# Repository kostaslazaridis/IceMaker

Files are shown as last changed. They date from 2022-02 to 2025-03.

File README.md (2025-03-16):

I came across a broken ice maker. Eager to repair it, I discovered that the original PCB was destroyed due to a burned-out IC, making it irreparable. Instead of giving up, I decided to reverse engineer the ice maker's electronics to recreate a working control board from scratch.
https://www.youtube.com/watch?v=2SMoJ112lBk&t=18s

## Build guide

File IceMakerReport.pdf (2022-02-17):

### ΠΟΛΥΤΕΧΝΕΙΟ ΚΡΗΤΗΣ

ΣΧΟΛΗ ΗΛΕΚΤΡΟΛΟΓΩΝ ΜΗΧΑΝΙΚΩΝ ΚΑΙ ΜΗΧΑΝΙΚΩΝ ΥΠΟΛΟΓΙΣΤΩΝ

### Αυτοματοποίηση παρασκευαστή παγοκύβων

### «Ειδικά Θέματα σε Συστήματα Ηλεκτρικών Μετρήσεων» (ΗΡΥ602)

### ΛΑΖΑΡΙΔΗΣ ΚΩΝΣΤΑΝΤΙΝΟΣ

### 2 Ειδικά Θέματα σε Συστήματα Ηλεκτρικών Μετρήσεων

# Πρόλογος

Η εργασία αυτή αφορά την επισκευή μιας παγομηχανής. Συγκεκριμένα, είχε καταστραφεί η πλακέτα και μέρος του κάδου. Θα ήθελα να ευχαριστήσω προσωπικά τον καθηγητή Καλαϊτζάκη Κωσταντίνο για την ευκαιρία που μου έδωσε να συμμετέχω στο μάθημα αυτό.

# Περίληψη

Το θέμα της εργασίας είναι η δημιουργία του κυκλώματος για τον έλεγχο μιας παγομηχανής. Ο μικροεπεξεργαστής που χρησιμοποιήθηκε, είναι το Arduino Nano το οποίο επεξεργάζεται τα δεδομένα από τους αισθητήρες και τις εισόδους που δίνει ο χρήστης ώστε να δημιουργήσει παγοκύβους. Στη συγκεκριμένη εργασία, φαίνεται η χρήση αλγορίθμου για την ανάγνωση της θερμοκρασίας καθώς και η εύρεση της καμπύλης θερμοκρασίας-αντίστασης από άγνωστο θερμόμετρο, η χρήση μεταλλικής γειωμένης πλάκας για την αποφυγή ηλεκτρομαγνητικών παρεμβολών, η μελέτη των εξαρτημάτων που χρησιμοποιήθηκαν, η κατασκευή της πλακέτας καθώς και ο προγραμματισμός ενός σύνθετου προβλήματος.

# Περιεχόμενα

## 1. Γενικά

Η αρχή λειτουργίας της παγομηχανής είναι η συμπίεση του αέριου(δηλ. εφαρμογή υψηλής πίεσης) και στη συνέχεια η ψύξη του μέσω μιας ψύκτρας και ενός ανεμιστήρα. Πλέον η θερμοκρασία του συμπιεσμένου αερίου βρίσκετε κοντά στην θερμοκρασία του δωματίου. Καθώς το αέριο περνάει από μία βαλβίδα η πίεση και η θερμοκρασία του μειώνονται ραγδαία. Στη συνέχεια κατευθύνεται σε σωλήνες οι οποίες βρίσκονται σε επαφή με το νερό και λόγω της διαφοράς θερμοκρασίας, το αέριο απορροφά θερμότητα από το νερό και μέσα σε λίγα λεπτά το νερό παγώνει. Για να αφαιρεθούν οι παγοκύβοι από τα μεταλλικά στοιχεία υπάρχει μια βαλβίδα η οποία εξισορροπεί τις πιέσεις. Όταν οι πιέσεις εξισορροπηθούν τα στοιχεία αυτά θερμαίνονται ελάχιστα και η εσωτερική πλευρά των παγοκύβων λιώνει, αυτό είναι αρκετό ώστε να τους επιτραπεί να «γλιστρήσουν» και να πέσουν στο κάδο περισυλλογής.

## 1. Αρχή λειτουργίας

Το παρακάτω διάγραμμα ροής περιγράφει τον αλγόριθμο λειτουργίας της παγομηχανής. Αρχικά υπάρχει μία κατάσταση InitialState στην οποία ο συμπιεστής είναι απενεργοποιημένος και η βαλβίδα αποσυμπίεσης είναι ανοιχτή, ώστε να μην υπάρχουν πιέσεις στο συμπιεστή, οι οποίες του προκαλούν μεγάλες φθορές. Επίσης σε αυτή την κατάσταση αδειάζει μια φορά το δοχείο ψύξης νερού, ώστε να μην υπάρχουν παγοκύβοι ή νερό και έτσι εξασφαλίζεται η ομαλή λειτουργία του. Όταν ο χρήστης πατήσει το κουμπί λειτουργίας, ο αλγόριθμος ελέγχει αν το δοχείο περισυλλογής παγοκύβων είναι γεμάτο. Στη περίπτωση που δεν είναι γεμάτο ξεκινά η διαδικασίας δημιουργίας παγοκύβων ανάλογα με το πιο μέγεθος έχει επιλέξει ο χρήστης. Αυτή η διαδικασία επαναλαμβάνεται έως ότου το δοχείο περισυλλογής παγοκύβων γεμίσει είτε ο χρήστης να πατήσει το διακόπτη παύσης.

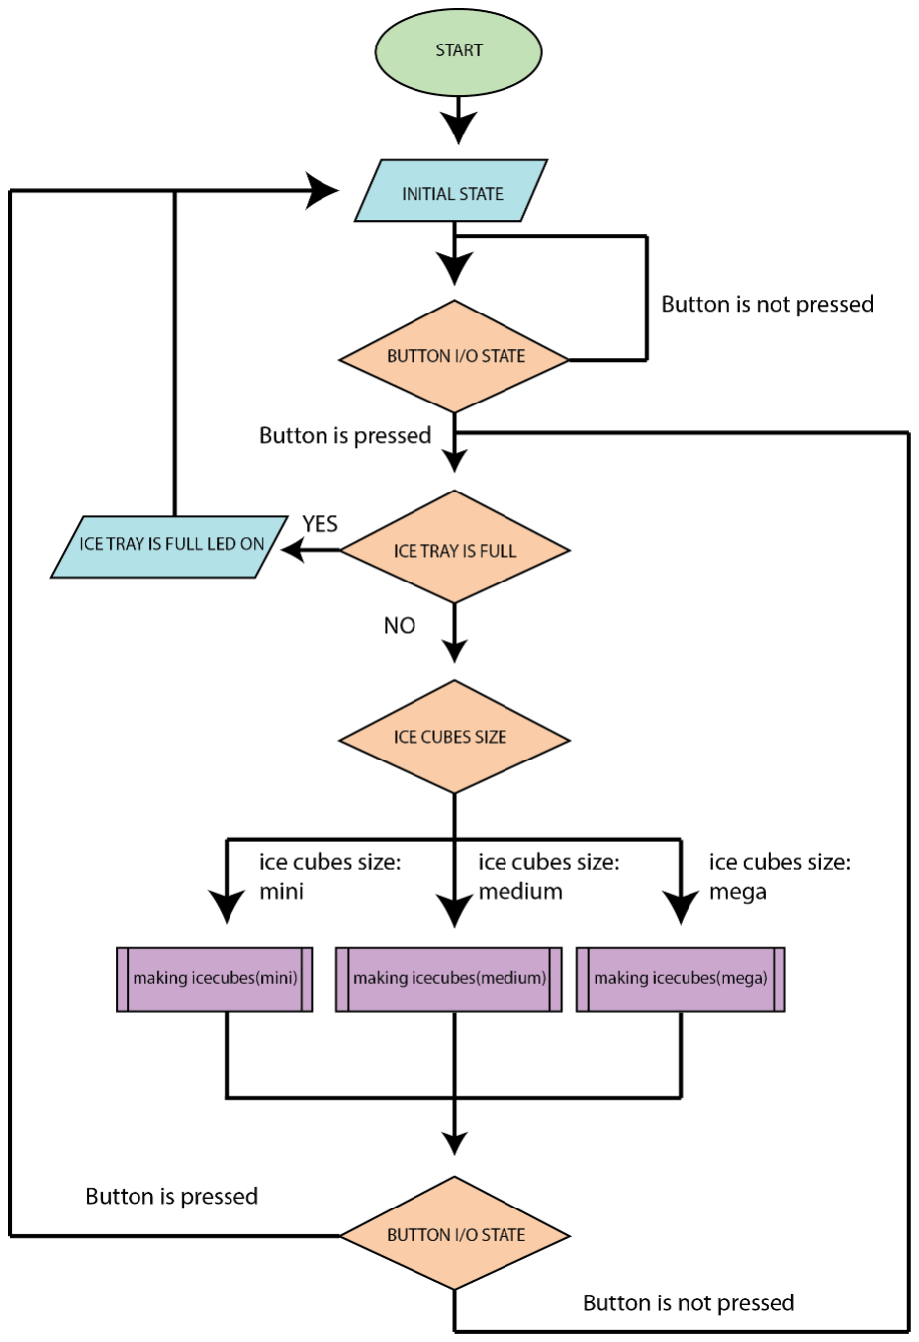
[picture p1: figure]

Εικόνα 1.1 Διάγραμμα ροής της λειτουργείας

Ο αλγόριθμος δημιουργίας παγοκύβων ξεκινά με την τοποθέτηση του δοχείου ψύξης νερού στη κατάλληλη θέση ώστε να γεμίσει με νερό. Στη συνέχεια, η αντλία λειτουργεί για καθορισμένο χρονικό διάστημα εκτός αν δεν υπάρχει νερό, οπότε απενεργοποιείτε και επιστρέφει στην InitialState. Αν υπάρχει νερό, ο συμπιεστής ενεργοποιείτε, η βαλβίδα αποσυμπίεσης απενεργοποιείτε για προκαθορισμένο χρόνο ανάλογα το μέγεθος παγοκύβων που επιθυμεί ο χρήστης. Τέλος ο συμπιεστής απενεργοποιείτε, η βαλβίδα αποσυμπίεσης ενεργοποιείτε και τα παγάκια μεταφέρονται στο καλάθι περισυλλογής.

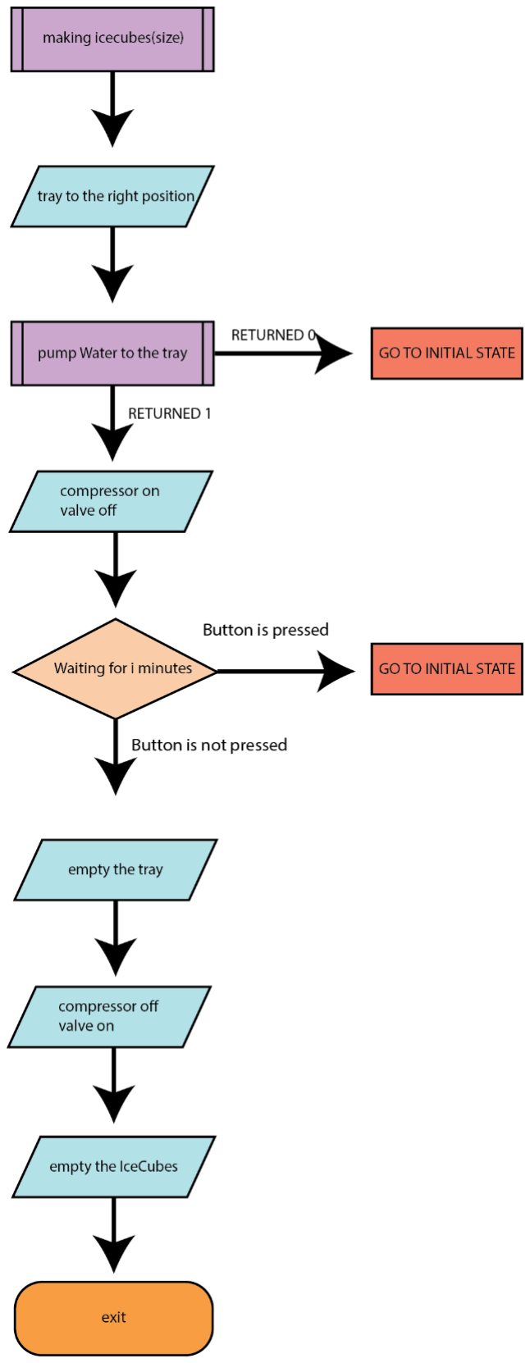
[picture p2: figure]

Εικόνα 1.2 Διάγραμμα ροής Δημιουργίας Παγοκύβων

Ο αλγόριθμος χρήσης της αντλίας αρχικά την ενεργοποιεί και σε κάθε κύκλο ρολογιού ελέγχει αν υπάρχει νερό. Στη περίπτωση που δεν υπάρχει, απενεργοποιεί την αντλία και ενημερώνει τον χρήστη.

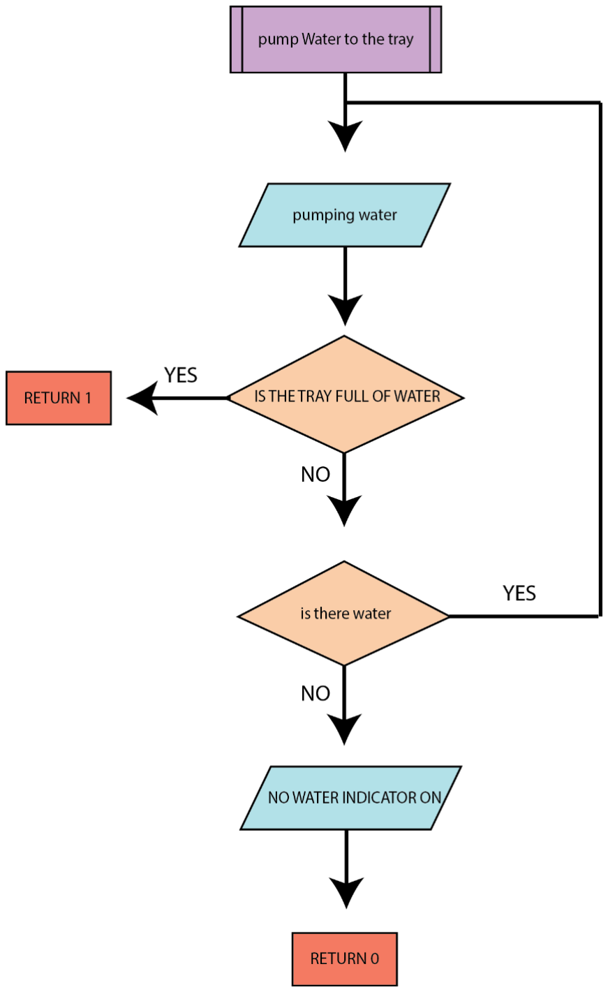
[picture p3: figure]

Εικόνα 1.3 Διάγραμμα ροής Αντλίας

## 2. Εισαγωγικά

## 2.1 Γενικές παρατηρήσεις

Στη συγκεκριμένη διατριβή, παρατηρήθηκε ότι η ηλεκτρομαγνητική ακτινοβολία λόγω του συμπιεστή δημιουργούσε παρεμβολές στον μικροεπεξεργαστή και λόγω των ευαίσθητων κυκλωμάτων «καιγόταν». Λόγω αυτής της παρεμβολής απαραίτητη θεωρείται η χρήση μίας γειωμένης επιφάνειας αλουμινίου ώστε να γειώνονται οι παρεμβολές και να μην επηρεάζουν τον μικροεπεξεργαστή. Παρατηρήθηκε επίσης ότι στην αρχή λειτουργίας της αντλίας υπήρχε μια σημαντική πτώση τάσης, η οποία έκανε επανεκκίνηση στον μικροεπεξεργαστή με αποτέλεσμα την μη ορθή εκτέλεση του προγράμματος. Κάθε relay ελέγχεται από transistor ώστε να μην απορροφηθεί περισσότερο ρεύμα από τι μπορεί να διαθέσει ο μικροεπεξεργαστής. Παρατηρήθηκε ότι αν δεν καθαριστεί αρκετά καλά το flux (πάστα που βοηθά την κόλληση) μπορεί να προκαλέσει βραχυκλώματα που θα επηρεάσουν το κύκλωμα.

## 2.2 Επικοινωνία μικροελεγκτή με τα εξαρτήματα του συστήματος

Στο παρακάτω σχήμα φαίνονται οι συνδέσεις του μικροεπεξεργαστή με τα εξαρτήματα. Τα βέλη που κατευθύνονται στο Arduino είναι οι είσοδοι ενώ τα βέλη που ξεκινούν από αυτό είναι τα εξαρτήματα που ελέγχει.

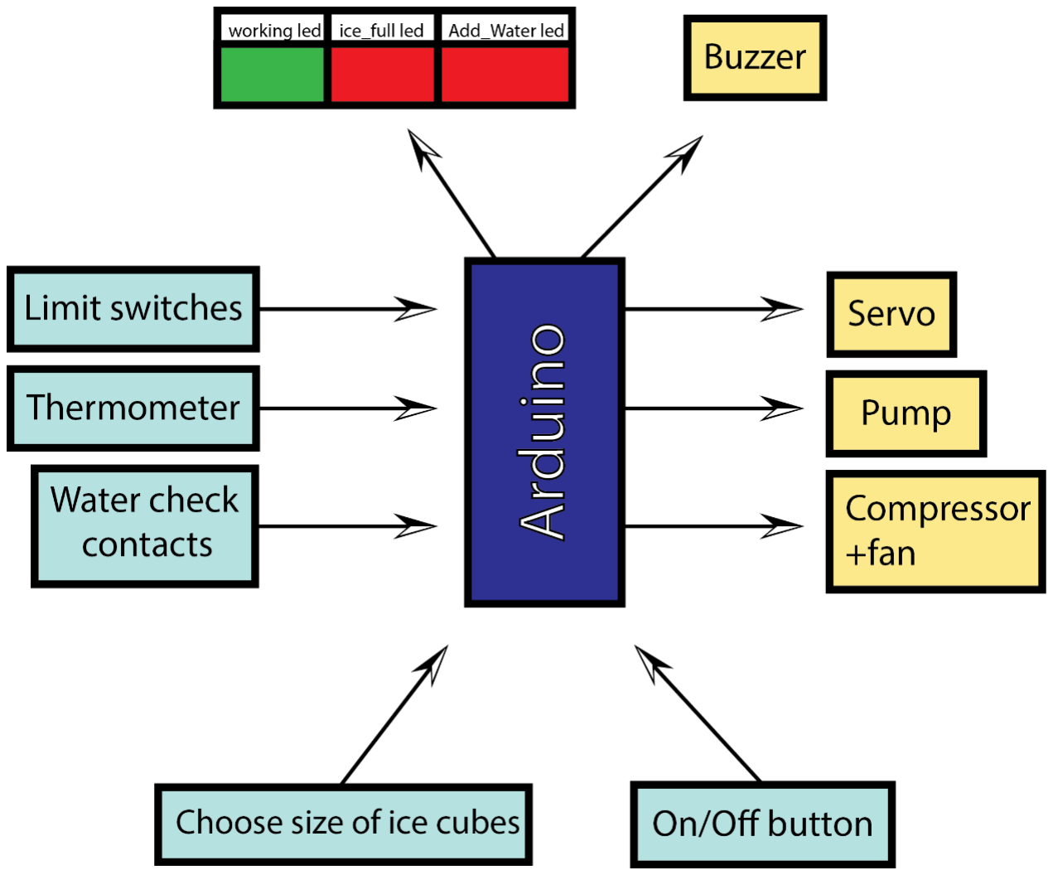
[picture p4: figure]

Εικόνα 2.1 Abstract σχέδιο κυκλώματος

## 2.3 Αισθητήρες που χρησιμοποιήθηκαν

- Αισθητήρας νερού:

Ο αισθητήρας αυτός αποτελείται από δύο ελάσματα τα οποία βρίσκονται αρκετά κοντά. Όταν διέρχεται από αυτόν τον αισθητήρα νερό, λόγω των ηλεκτρολυτών υπάρχει αντίσταση(της τάξης Mega Ohm) η οποία δημιουργείται στα δύο ελάσματα που προαναφέρθηκαν. Στη συνέχεια, ο μικροεπεξεργαστής εντοπίζει την αντίσταση αυτή, η οποία σηματοδοτεί την ύπαρξη νερού.

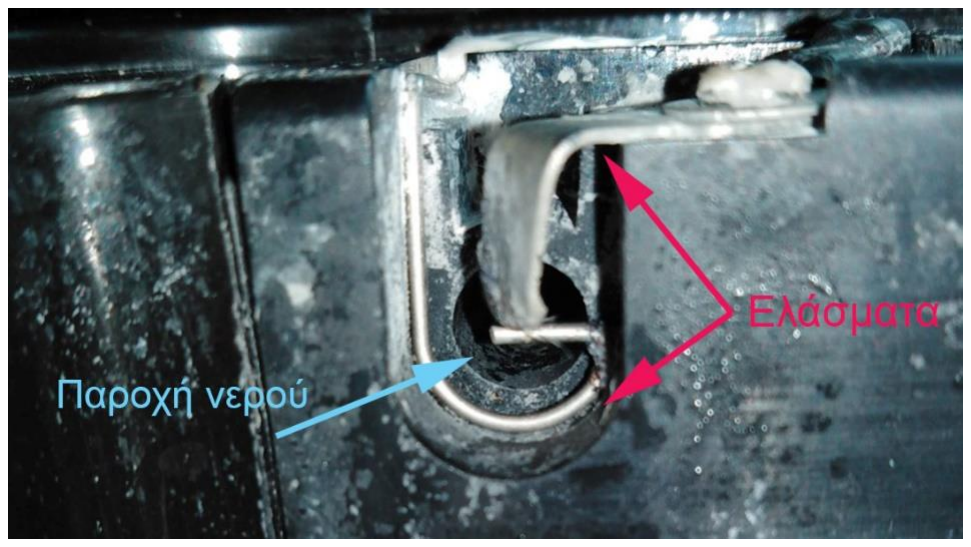
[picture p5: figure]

- Αισθητήρας θερμοκρασίας:

Ο αισθητήρας αυτός είναι ένα θερμίστορ τύπου NTC το οποίο μετρά τη θερμοκρασία στην άκρη του δοχείου περισυλλογής παγοκύβων. Όταν η θερμοκρασία αυτή προσεγγίζει τους μηδέν βαθμούς κελσίου, το οποίο σημαίνει ότι κάποιο παγάκι είτε ακουμπάει είτε είναι αρκετά κοντά, σηματοδοτείται ότι το καλάθι είναι γεμάτο με παγάκια και η διαδικασία δημιουργίας παγοκύβων πρέπει να σταματήσει.

Εικόνα 2.2 Εικόνα Αισθητήρα Νερού

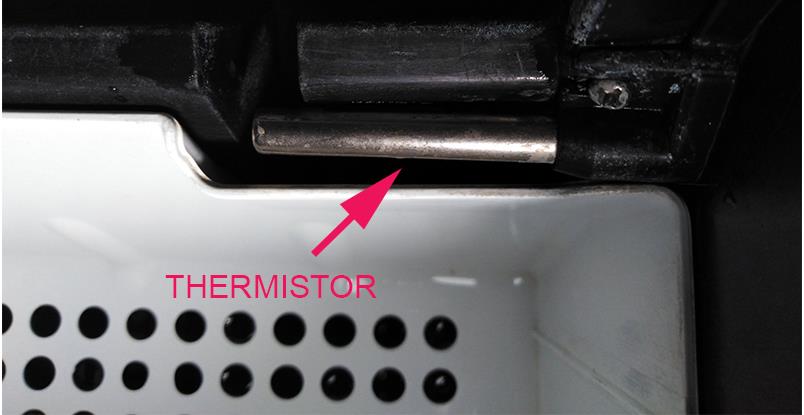
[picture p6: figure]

Εικόνα 2.3 Εικόνα Θερμίστορ

## 2.4 Μοτέρ για την κίνηση του δοχείου ψύξης νερού

- Servo 360°

Το μοτέρ που κινεί το δοχείο αυτό είναι ένα servo τριακοσίων εξήντα μοιρών, το οποίο δέχεται ένα παλμικό σήμα από τον μικροεπεξεργαστή που καθορίζει την κατεύθυνση και την ταχύτητα. Το μοτέρ αυτό αντικατέστησε το προϋπάρχον, το οποίο ήταν ένα Ac-motor που παρέμενε στις τερματικές θέσεις έως ότου άλλαζε κατεύθυνση από το μαγνητικό πεδίο. Ωστόσο, αυτός ο μηχανισμός ήταν προβληματικός στο συγκεκριμένο σύστημα, καθώς η άσκηση πίεσης στις τερματικές θέσεις τις έφθειρε και τελικά έσπασε τμήμα του κάδου. Η βλάβη αναπληρώθηκε με τρισδιάστατα σχεδιασμένο και εκτυπωμένο εξάρτημα που παρατίθεται παρακάτω.

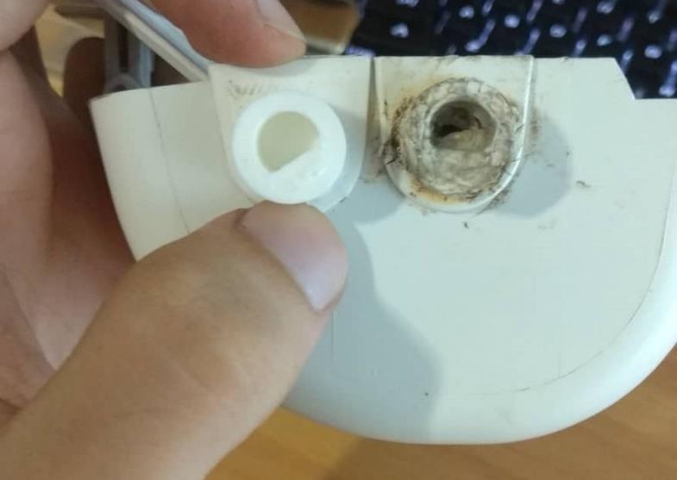
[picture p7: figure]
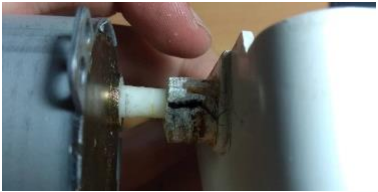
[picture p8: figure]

Εικόνα 2.4 Κάδος ψύξης νερού

## 3. Μελέτη εξαρτημάτων

### 3.1 Μελέτη κυματομορφής αντλίας και βελτιστοποίηση

Λόγω της κατασκευής της αντλίας και συγκεκριμένα στο σημείο που ενώνονται οι συλλέκτες με τα καρβουνάκια, προκύπτουν περιοδικά στην κυματομορφή του ρεύματος σημεία μηδενισμού και έπειτα απότομης αύξησης του ρεύματος. Το γεγονός αυτό ενδέχεται να επηρεάσει το τροφοδοτικό που είναι power switching supply και να του μηδενίσει την τάση εξόδου.

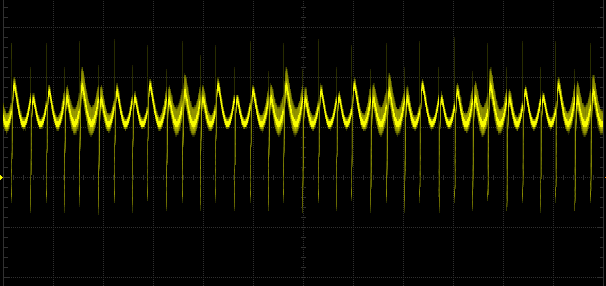
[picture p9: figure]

Για να ομαλοποιήθεί αυτή η απότομη μεταβολή του ρεύματος τοποθετήθηκε παράλληλα ένας πυκνωτής των 470μF ο οποίος επιλέχθηκε πειραματικά. Λόγω του ότι το θεμελιώδες εξάρτημα της αντλίας είναι ένα DC motor ενδέχετε να επιστρέψει τάση (kickback), για την μείωση της φθοράς του transistor τοποθετήθηκε μία δίοδος ώστε το ρεύμα αυτό να καταναλωθεί απ’τη δίοδο.

Εικόνα 3.1 Κυματομορφή ρεύματος αντλίας

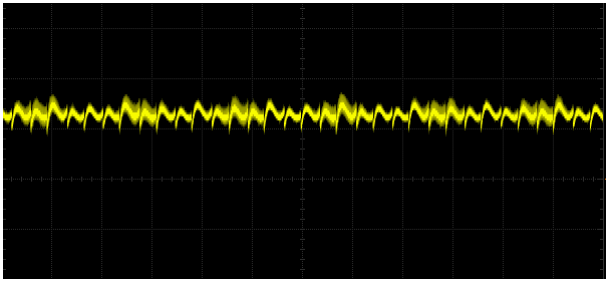
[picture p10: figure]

Εικόνα 3.2 Κυματομορφή ρεύματος αντλίας συνδεδεμένη με πυκνωτή και δίοδο παράλληλα

## 3.1 Υπολογισμός Πυκνωτή στην είσοδο του Μικροεπεξεργαστή

Παρακάτω παρατίθονται οι κυματομορφές ρεύματος της αντλίας και της τάσης του τροφοδοτικού. Παρατηρείται ότι για περίπου 6,3 ms καταναλώνει ένα μεγαλύτερο ρεύμα το οποίο δημιουργεί μία βύθιση στην τάση του τροφοδοτικού, όπως φαίνεται στην Εικόνα 3.4. Αυτή η μεταβολή της τάσης κάνει reset στο Arduino. Γι’ αυτό το λόγο στην είσοδο τάσης του μικροεπεξεργαστή τοποθετήθηκε μια δίοδος και ένας πυκνωτής (Εικόνα 3.7) ώστε όταν γίνετε βύθιση, η τάση τροφοδοσίας του μικροεπεξεργαστή να είναι σταθερή.

Εικόνα 3.3 Κυματομορφή ρεύματος αντλίας

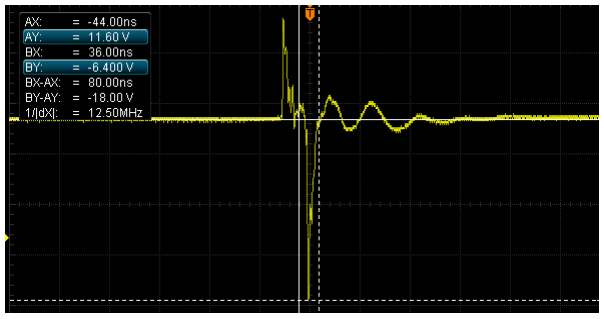
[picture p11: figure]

Εικόνα 3.4 Κυματομορφή τάσης τροφοδοσίας

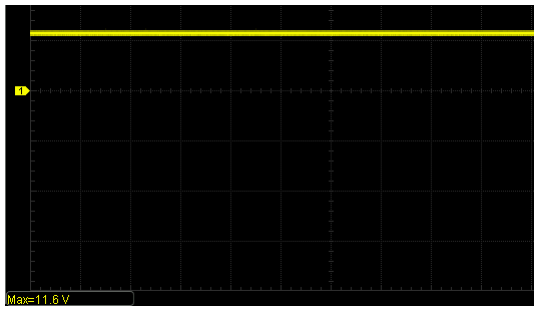
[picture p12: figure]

Εικόνα 3.5 Κυματομορφή τάσης τροφοδοσίας μικροεπεξεργαστή

Για τον υπολογισμό του κατάλληλου πυκνωτή πρέπει να παρατηρηθεί η καμπύλη αποφόρτισης του. Φαίνεται ότι σε χρόνο 0.7T η τάση του πυκνωτή έχει μειωθεί κατά 50%. Η τάση τροφοδοσίας του Arduino ιδανικά πρέπει να κυμαίνεται από 12 έως 6 volt. Με δεδομένο ότι η τάση που παρέχεται σε αυτό είναι 12 V ο πυκνωτής πρέπει να μπορεί να κρατά την τροφοδοσία έως τα 6 V για τουλάχιστον 80ns (χρόνος βύθισης τάσης λόγω αντλίας). Αξιοσημείωτο είναι ότι για τον υπολογισμό αυτό μελετάται η ακραία περίπτωση, κατά την οποία ο μικροεπεξεργαστής καταναλώνει τη μέγιστη δυνατή τιμή ρεύματος που μπορεί να του παρέχεται μέσω του regulator, πράγμα που είναι αδύνατο στο συγκεκριμένο κύκλωμα και η κατανάλωση αυτή στην πραγματικότητα είναι υπερβολικά πιο μικρή. Γι’ αυτό το λόγο η τιμή του πυκνωτή θα υπολογιστεί αποκλειστικά από την κυμματομορφή αποφόρτισης τάσης.

Αρχικά για τον υπολογισμό του πυκνωτή βρέθηκε πόσο είναι το μέγιστο ρεύμα που μπορεί να καταναλωθεί από το Arduino. Το ρεύμα αυτό είναι το μέγιστο που μπορεί να καταναλωθεί απ’ το regulator το οποίο με την σειρά του παρέχει ρεύμα στο μικροελεγκτή. Η τιμή του είναι 1.3 A και η τάση που παρέχετε στο regulator στην ακραία περίπτωση είναι 6 V. Μέσω του νόμου του Ohm βρίσκεται η αντίσταση που θα βλέπει ως φορτίο ο πυκνωτής.

RA =

V
I

=

6
1.3

= 4.61 Ω

Θεωρώντας το κύκλωμα ως RC και Τ=80ns χρόνος αποφόρτισης του πυκνωτή. Η τιμή του πυκνωτή θα υπολογιστεί από τον τύπο:

T = 0.7 ∙ RA ∙ C ⇒ C =

T
0.7 ∙ RA

=

80ns
0.7 ∙ 4.61 Ω

= 24.7 nF

Για λόγους ασφαλείας η χωρητικότητα του πυκνωτή θα αυξηθεί και η τιμή του θα είναι 1000 μF.

Εικόνα 3.6 Εκφόρτιση πυκνωτή

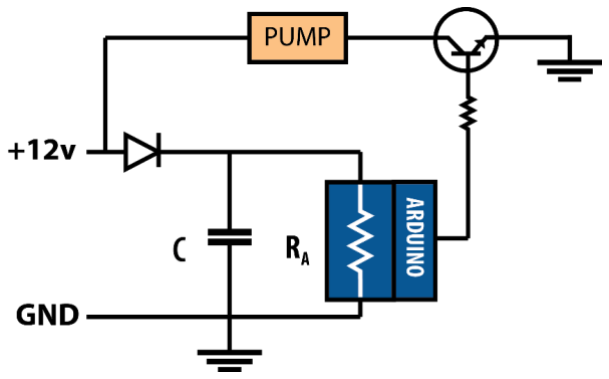
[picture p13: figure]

Εικόνα 3.7 Διάταξη Arduino Διόδου και πυκνωτή

## 3.2 Current limiting resistor LED

Για τον υπολογισμό των αντιστάσεων βρέθηκε η πτώση τάσης στο κάθε LED η οποία είναι 2.5V και το ρεύμα που είναι 3mA. Από τον νόμο του Ohm μπορεί να βρεθεί η αντίσταση που θα περιορίζει το ρεύμα:

R =

VGPIO − VF

ILED

=

5 − 2.5
0.003 = 830Ω

## 3.3 Relay και Δίοδος

Το relay ή αλλιώς ηλεκτρονόμος είναι ένας ηλεκτρικός διακόπτης (https://el.wikipedia.org/wiki/%CE%94%CE%B9%CE%B1%CE%BA%CF%8C%CF%80%CF%84%CE%B7%CF%82) που ανοίγει και κλείνει ένα ηλεκτρικό κύκλωμα (https://el.wikipedia.org/wiki/%CE%97%CE%BB%CE%B5%CE%BA%CF%84%CF%81%CE%B9%CE%BA%CF%8C_%CE%BA%CF%8D%CE%BA%CE%BB%CF%89%CE%BC%CE%B1) κάτω από τον έλεγχο ενός άλλου ηλεκτρικού κυκλώματος, στη συγκεκριμένη διατριβή τα GPIO Ports του Arduino. Αποτελείται από ένα πηνίο το οποίο όταν το διαρρέει ηλεκτρικό ρεύμα (https://el.wikipedia.org/wiki/%CE%97%CE%BB%CE%B5%CE%BA%CF%84%CF%81%CE%B9%CE%BA%CF%8C_%CF%81%CE%B5%CF%8D%CE%BC%CE%B1) το παραγόμενο μαγνητικό πεδίο (https://el.wikipedia.org/wiki/%CE%9C%CE%B1%CE%B3%CE%BD%CE%B7%CF%84%CE%B9%CE%BA%CF%8C_%CF%80%CE%B5%CE%B4%CE%AF%CE%BF) έλκει έναν οπλισμό που είναι μηχανικά συνδεδεμένος σε μια κινούμενη επαφή. Όπως προαναφέρθηκε όταν στο πηνίο του ηλεκτρονόμου υπάρχει τάση δημιουργείται μαγνητικό πεδίο. Όταν διακοπεί η τάση τότε το μαγνητικό πεδίο το οποίο υπήρχε γύρω του αντλείται από το πηνίο και δημιουργεί ένα ανάστροφο ρεύμα. Το ρεύμα αυτό περνάει μέσα από τη δίοδο και δεν επηρεάζει το υπόλοιπο κύκλωμα.

Εικόνα 3.8 Διάταξη LED αντίστασης

Εικόνα 3.9 Διάταξη relay διόδου

## 3.4 Pull-down Αντιστάσεις για τους διακόπτες

Στη συγκεκριμένη διατριβή χρησιμοποιήθηκαν διακόπτες Momentary-Push buttons όπου η συγκεκριμένη εντολή στον Μικροεπεξεργαστή δηλώνεται με λογικό «1». Αν στο διακόπτη αυτόν δεν χρησιμοποιηθεί αντίσταση ώστε το σήμα να γειώνετε, όταν δεν πιέζεται θα λαμβάνει σήματα από το γύρω ηλεκτρομαγνητικό θόρυβο το οποίο συνεπάγεται ασταθή συμπεριφορά του κυκλώματος. Γι’ αυτό το λόγο τοποθετείται μια αντίσταση στο σήμα εισόδου και στη γείωση. Η αντίσταση αυτή δεν επιτρέπεται να είναι ούτε μηδενική (λόγω του ότι θα προκαλεί βραχυκύκλωμα στη πηγή και συνεπώς καταστροφή του regulator του Arduino) αλλά ούτε και άπειρη για τους λόγους που προαναφέρθηκαν. Στον επεξεργαστή, η ελάχιστη προτεινόμενη αντίσταση που μπορεί να τοποθετηθεί είναι 20 kΩ ενώ η μέγιστη είναι 50 kΩ. Όσο πλησιάζει η αντίσταση το μέγιστο όριο, τόσο θεωρείται πιο «αδύναμη» ενώ στην περίπτωση που πλησιάζει το ελάχιστο όριο θεωρείται «δυνατή». Η επιλογή της αντίστασης βρίσκετε πειραματικά.

Εικόνα 3.10 Διάταξη pull down resistors

Εικόνα 3.11 Διάγραμμα pull down αντίστασης

## 3.5 Υπολογισμός καμπύλης αισθητήρα θερμοκρασίας αντίστασης πειραματικά

Λόγω του ότι η καμπύλη του αισθητήρα αυτού ήταν άγνωστη έπρεπε να βρεθεί πειραματικά. Στη συνέχεια έπρεπε να βρεθεί μια συνάρτηση που θα πλησιάζει αρκετά κοντά σε αυτή την καμπύλη, ώστε να μπορέσει ο μικροεπεξεργαστής να υπολογίζει τις θερμοκρασίες ανάλογα με την αντίσταση που θα έχει εκείνη την στιγμή ο αισθητήρας. Λόγω της μη γραμμικότητας της, η εύρεση της είναι αρκετά δύσκολη. Γι’ αυτό τον λόγο υπολογίστηκε μέσω του Matlab με τεχνητή νοημοσύνη.

- Αρχικά έπρεπε να γίνουν μετρήσεις θερμοκρασίας και αντίστασης του θερμομέτρου. Για να υπάρχει μια ικανοποιητική ακρίβεια στις μετρήσεις χρησιμοποιήθηκαν 2 θερμόμετρα. Στη συνέχεια αφαιρέθηκαν κάποιες μετρήσεις οι οποίες υπήρχαν λόγω σφάλματος των οργάνων. Τέλος έγινε το γράφημα των μετρήσεων και βρέθηκε η εξίσωση η οποία τείνει στην αρχική καμπύλη των μετρήσεων.

Η εξίσωση είναι ένα πολυώνυμο 5ου βαθμού:

P(R) = −0.0000039 ∙ R

5 + 0.0006 ∙ R

4 − 0.0351 ∙ R

3 + 1.026 ∙ R

2 − 15.7405 ∙ R

1 + 106.0322

Για την εύρεση της εξίσωσης χρησιμοποιήθηκε η συνάρτηση polyfit του Matlab

Εικόνα 3.12 Διάγραμμα του αισθητήρα θερμοκρασίας Θερμοκρασία-Αντίσταση. Πειραματικά αποτελέσματα(Original) και η πολυονυμική εξίσωση που το προσομοιώνει (predicted)

Εικόνα 3.13 Κώδικας Matlab

## 3.6 Υπολογισμός αντιστάσεων για τα transistors

Λόγω του ότι το κύκλωμα δεν έχει ιδιαίτερες απαιτήσεις ούτε στα ρεύματα, ούτε στις συχνότητες χρησιμοποιείται το 2n2222. Γενικά, το transistor λειτουργεί ως ενισχυτής. Όμως στη συγκεκριμένη περίπτωση το transistor χρησιμοποιείται ως διακόπτης με κατάσταση “ON” όταν η τάση στην είσοδο είναι υψηλή και “OFF” όταν είναι χαμηλή. Στα transistor υπάρχει μια περιοχή στην οποία όσο περισσότερο είναι το ρεύμα εισόδου στη βάση, τόσο μεγαλύτερο ρεύμα επιτρέπει να διαρρέεται μέσω αυτού. Στη συγκεκριμένη περίπτωση δε θα μελετηθεί αυτή η περιοχή, θα μελετηθεί μόνο στα Cut-off και στο Saturation. Μια τυπική σύνδεση του transistor φαίνεται παρακάτω όπου η τάση in συνδέεται στο GPIO port όπου R2 συμβολίζει το φορτίο.

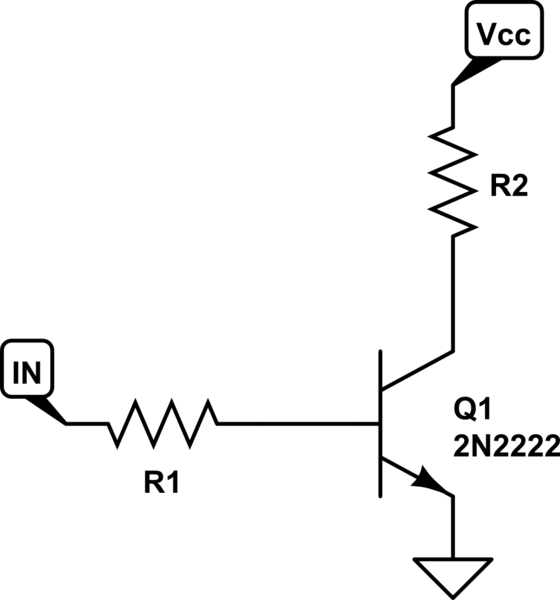
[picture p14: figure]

- Υπολογισμός αντιστάσεως εισόδου R1

Για τον υπολογισμό της αντιστάσεως εισόδου βάσης του transistor θα θεωρηθεί ότι το transistor διαχειρίζεται το μέγιστο ρεύμα, το οποίο είναι 500mA. Η τάση τροφοδοσίας Vcc είναι 12V η οποία λόγω της πτώσης τάσης που υπάρχει στο transistor θα έχει μια πτώση τάσης κατά μέγιστο 1.2V αυτό είναι ανεκτό από τα στοιχεία που ελέγχει. Λόγω του ότι η τάση μειώνεται το ρεύμα θα αυξηθεί, το οποίο είναι ανεκτό διότι τα στοιχεία καταναλώνουν περίπου το μισό ρεύμα από τι μπορεί να διαχειριστεί το transistor. Η τάση στη βάση πριν την αντίσταση είναι η τάση του GPIO port του μικροελεγκτή που είναι 5V. Το datasheet του transistor δηλώνει ότι όταν το ρεύμα Ic είναι 500mA τότε το ρεύμα της βάσης IB θα πρέπει να είναι 50mA, το μέγιστο όμως ρεύμα που μπορεί να παρέχει το Arduino είναι 40mA. Το VF είναι η πτώση τάσης λόγου της διόδου που σχηματίζεται από την βάση προς τον εκπομπό και είναι ίση με 0.7V. Με τον νόμο του Ohm μπορεί να υπολογιστεί εύκολα η αντίσταση R1.

R1 =

VGPIO − VF
IB

=

5 − 0.7 V
40mA = 107.5Ω

Εικόνα 3.14 Διάταξη transistor αντίστασης

## 3.7 Αισθητήρας Θερμοκρασίας-Νερού

O αισθητήρας θερμοκρασίας τοποθετήθηκε σε διάταξη διαιρέτη τάσης όπου η μία αντίσταση R1 είναι γνωστή. Λόγω του διαιρέτη τάσης είναι γνωστό ότι :

VOUT = VIN ∙ (

R2
R2 + R1

)

Αν αυτή η εξίσωση λυθεί ώς προς R2 :

R2 = R1 ∙ (

VIN

VOUT

− 1)

Οι αισθητήρες Θερμοκρασίας και Νερού ενώ ακολουθούν την αρχή διαφέρουν στην τιμή της γνωστής αντίστασης. Για τον αισθητήρα του νερού πρέπει να τοποθετηθεί μια μεγάλη αντίσταση R1 για να υπάρχει πτώση τάσης που θα μπορεί να διαβάσει ο μικροεπεξεργαστής, διότι η αντίσταση του νερού είναι αρκετά μεγάλη (Προσοχή: αν είναι υπερβολικά μεγάλη η αντίσταση μπορεί να μη γειώνεται σωστά το σήμα και να επηρεάζεται από παρεμβολές των ηλεκτρομαγνητικών σημάτων). Αντίθετα η αντίσταση R1 για τον αισθητήρα θερμοκρασίας πρέπει να είναι αρκετά μικρότερη ώστε να υπάρχει καλή ακρίβεια στην μετρήσεις.

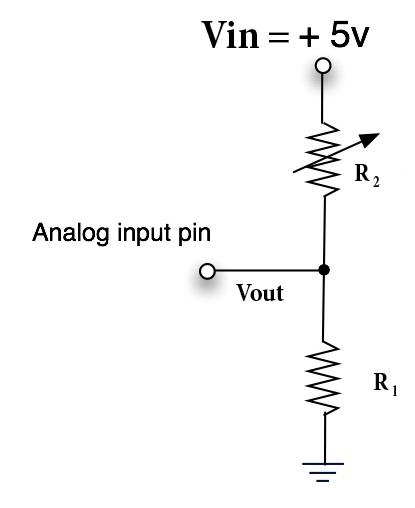
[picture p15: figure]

Εικόνα 3.15 Διάταξη διαιρέτη τάσης για αισθητήρες

## 3.8 Επιλογή μεγέθους Παγοκύβων

Λόγω του ότι χρησιμοποιούνται όλες οι ψηφιακές είσοδοι/έξοδοι του μικροεπεξεργαστή δεν είναι δυνατό να προστεθούν διακόπτες που θα επιλέγουν το μέγεθος των παγοκύβων. Γι’ αυτό το λόγο θα χρησιμοποιηθεί μια αναλογική είσοδος του Arduino στην οποία θα συνδεθούν με την παρακάτω διάταξη τρεις διακόπτες με τρεις διαφορετικές αντιστάσεις. Όταν ο χρήστης επιλέξει ένα μέγεθος, τότε βραχυκυκλώνεται μία από αυτές με μια γνωστή αντίσταση και δημιουργείται πτώση τάσης, την οποία θα διαβάζει ο μικροεπεξεργαστής μέσω της αναλογικής εισόδου και θα υπολογίζει με τον νόμο του Ohm την αντίσταση όπου επιλέχθηκε, συνεπώς ποιο μέγεθος παγοκύβων. Με την μέθοδο αυτή δίνετε η δυνατότητα να χρησιμοποιούνται αρκετοί διακόπτες σε μόνο μία είσοδο ώστε να μην δεσμεύονται οι υπόλοιπες.

Ο τύπος εύρεσης αντιστάσεως είναι ο ίδιος με τον παραπάνω που υπολογίστηκε στη παράγραφο «Αισθητήρας Θερμοκρασίας-Νερού»:

R2 = R1 ∙ (

VIN

VOUT

− 1)

Εικόνα 3.16 Διάταξη τρειών κουμπιών επιλογής

## 3.9 Μέγεθος Παγοκύβων

Έπειτα από μετρήσεις του μεγέθους παγοκύβων ανάλογα την ώρα που παγώνουν, παρατηρήθηκε ότι οι παγοκύβοι τείνουν να αυξάνονται με λογαριθμική σχέση. Το γεγονός αυτό είναι αναμενόμενο διότι καθώς αυξάνεται η διάμετρός απομακρύνεται το στέλεχος που ψύχετε απ’ το υγρής μορφής νερό. Παρακάτω παρατίθονται οι μετρήσεις και το διάγραμμα Χρόνου-Διαμέτρου:

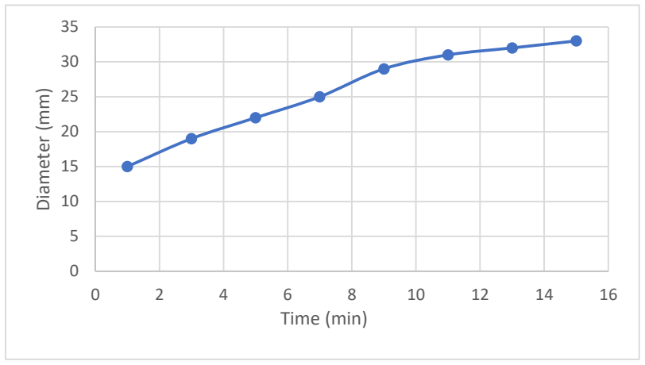
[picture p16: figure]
Diameter (mm); Time (min)

Minutes | Diameter
15 min | 33 mm
13 min | 32 mm
11 min | 31 mm
9 min | 29 mm
7 min | 25 mm
5 min | 22 mm
3 min | 19 mm
1 min | 15 mm

1

η Παρατήρηση: Λόγω του ότι το δοχείο συλλογής νερού επαναχρησιμοποιεί το νερό από τα λιωμένα παγάκια, η θερμοκρασία του νερού μειώνεται με αποτέλεσμα το νερό να παγώνει πιο γρήγορα. Συμπερασματικά τα παραπάνω αποτελέσματα δηλώνουν την γενική εκτύλιξη της διαδικασίας και όχι τους χρόνους που χρειάζεται για να παράγει ένα παγοκύβο συγκεκριμένης διαμέτρου.

2

η Παρατήρηση: Η μέγιστη διάμετρος παγοκύβου είναι συγκεκριμένη λόγω κατασκευής της παγομηχανής και δεν πρέπει να ξεπεραστεί διότι ενδέχεται να προκαλέσει βλάβη στο μηχάνημα.

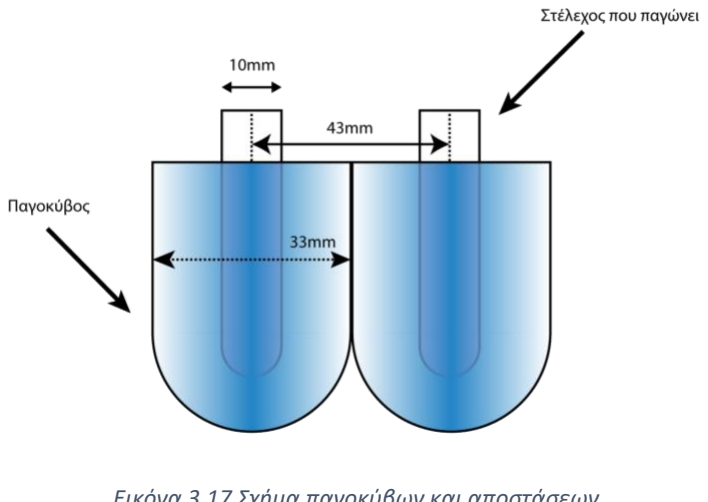
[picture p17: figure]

Εικόνα 3.17 Σχήμα παγοκύβων και αποστάσεων

## 4. Κώδικας Προγραμματισμού

## 4.1 Συνάρτηση delayForMinutesCompressor ()

Η συνάρτηση delay() που χρησιμοποιεί το Arduino αδρανοποιεί το σύστημα και δεν επιτρέπει να εκτελε-στεί άλλη εντολή μέχρι να τερματιστεί. Για τον λόγο αυτό δημιουργήθηκε μία συνάρτηση που δέχεται μια μεταβλητή float ως όρισμα, η οποία χρησιμοποιεί το εσωτερικό ρολόι του μικροεπεξεργαστή ώστε να περιμένει για το απαιτούμενο χρονικό διάστημα ελέγχοντας αν πατήθηκε ο διακόπτης παύσης. (https://forum.arduino.cc/index.php?topic=46540.0)

## 4.2 2.2 Συνάρτηση readTemp()

Η συνάρτηση αυτή είναι τύπου double και χρησιμοποιεί την εξίσωση που υπολογίστηκε παραπάνω (Υπολογισμός καμπύλης αισθητήρα θερμοκρασίας με αντίσταση). Μέσω του διαιρέτη τάσης υπολογίζεται η αντίσταση και στη συνέχεια μέσω της εξίσωσης η θερμοκρασία.

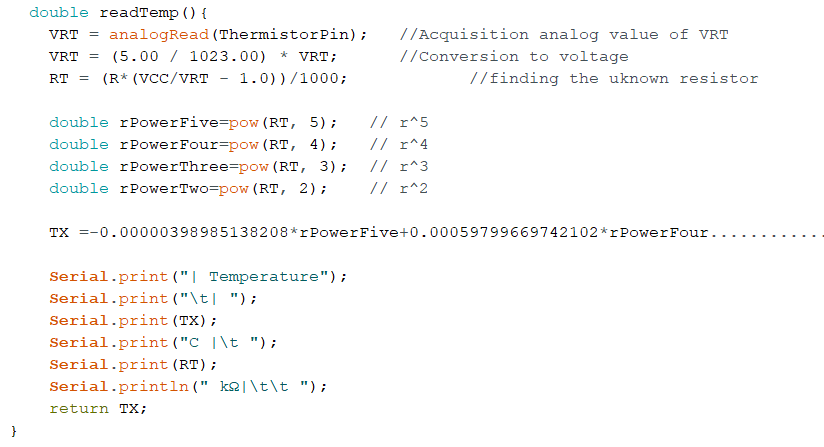
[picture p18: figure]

## 4.3 Συνάρτηση checkIfCartridgeIsFull()

Η συνάρτηση αυτή είναι τύπου Boolean και χρησιμοποιεί την παραπάνω συνάρτηση «readTemp()» ώστε όταν η θερμοκρασία είναι μικρότερη από την voudou μεταβλητή tempValueforFull να επιστρέψει true που υποδηλώνει ότι το δοχείο με τα παγάκια έχει γεμίσει.

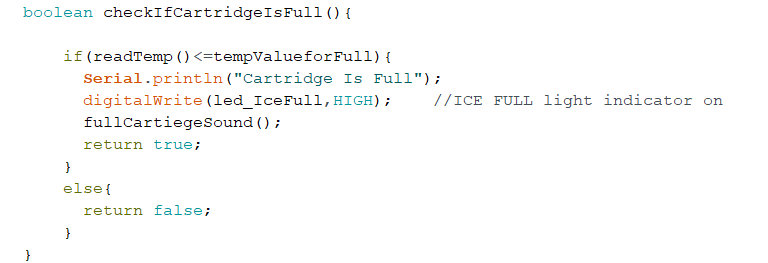
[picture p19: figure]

## 4.4 Συνάρτηση readButtonSelect()

Προκυμμένου να γίνει η επιλογή μεγέθους παγοκύβου η συνάρτηση αυτή ελέγχει την τάση στην αναλογική είσοδο και με τον νόμο του Ohm υπολογίζει την αντίσταση η οποία τοποθετείται, ανάλογα με το ποιο κουμπί πατήθηκε από τον χρήστη. Εν συνεχεία αλλάζει την μεταβλητή sizeOfIceCube που υποδηλώνει το μέγεθος των παγοκύβων.

## 4.5 Συνάρτηση toTheEndRight() - toTheEndLeft()

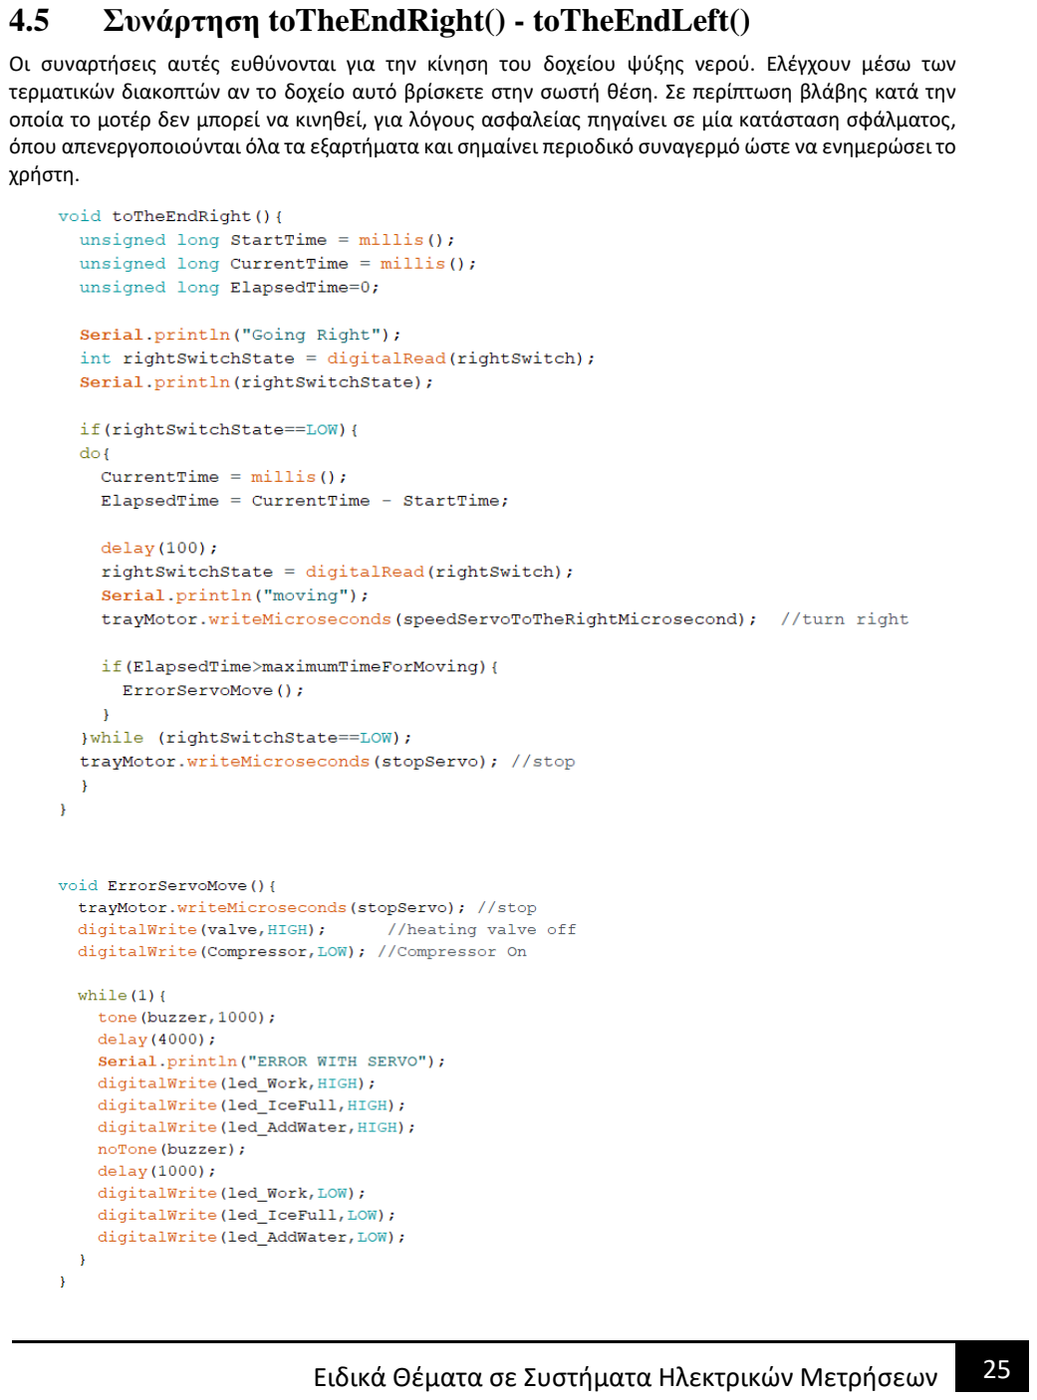
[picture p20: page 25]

Οι συναρτήσεις αυτές ευθύνονται για την κίνηση του δοχείου ψύξης νερού. Ελέγχουν μέσω των τερματικών διακοπτών αν το δοχείο αυτό βρίσκετε στην σωστή θέση. Σε περίπτωση βλάβης κατά την οποία το μοτέρ δεν μπορεί να κινηθεί, για λόγους ασφαλείας πηγαίνει σε μία κατάσταση σφάλματος, όπου απενεργοποιούνται όλα τα εξαρτήματα και σημαίνει περιοδικό συναγερμό ώστε να ενημερώσει το χρήστη.

## 4.6 Συνάρτηση checkNoWater()

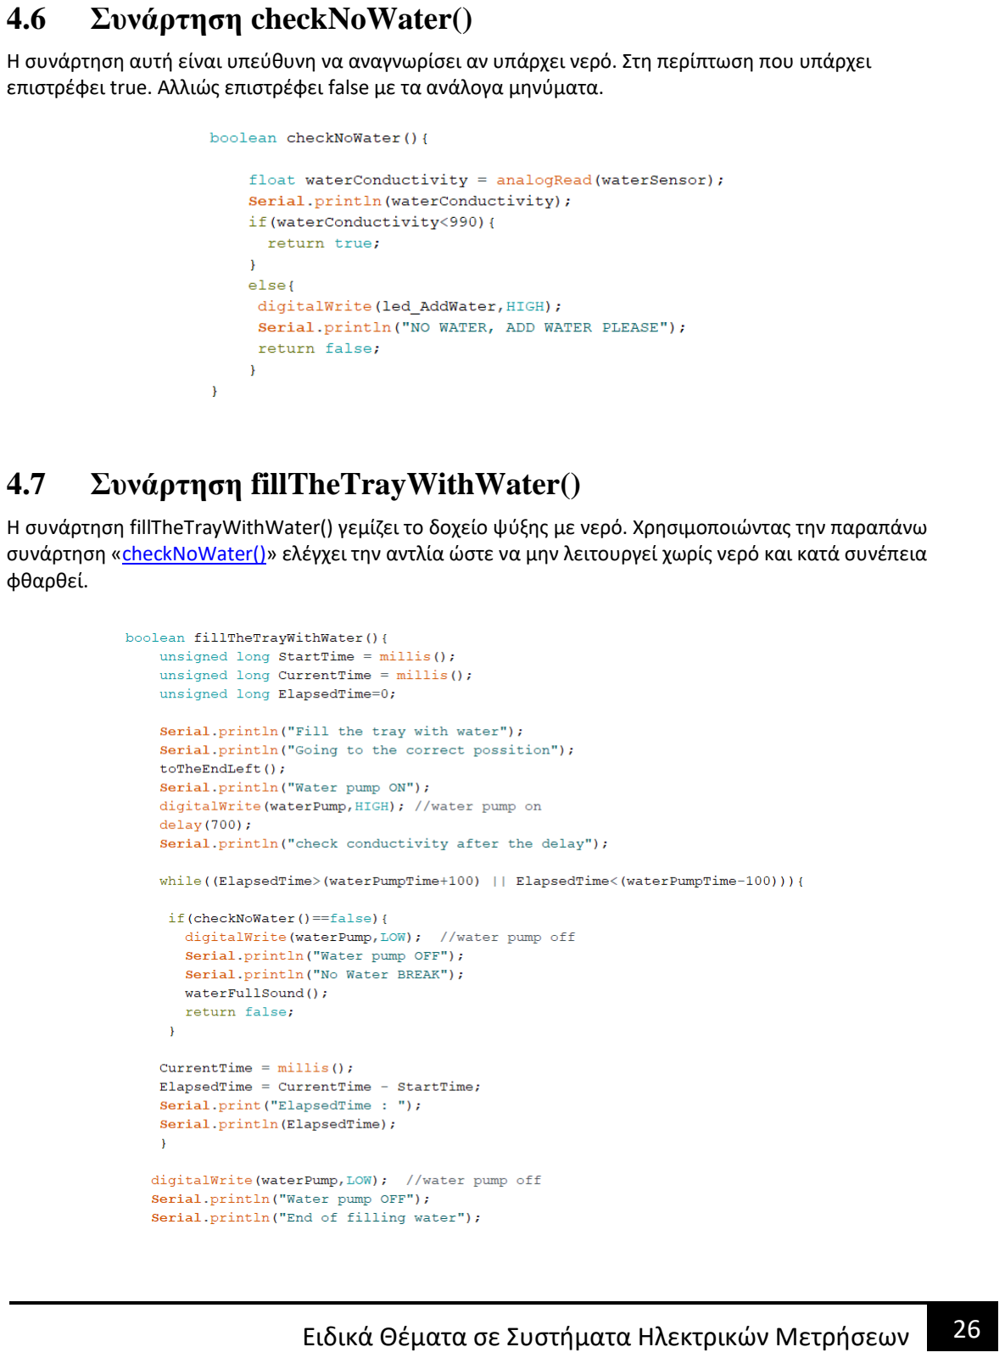
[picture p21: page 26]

Η συνάρτηση αυτή είναι υπεύθυνη να αναγνωρίσει αν υπάρχει νερό. Στη περίπτωση που υπάρχει επιστρέφει true. Αλλιώς επιστρέφει false με τα ανάλογα μηνύματα.

## 4.7 Συνάρτηση fillTheTrayWithWater()

Η συνάρτηση fillTheTrayWithWater() γεμίζει το δοχείο ψύξης με νερό. Χρησιμοποιώντας την παραπάνω συνάρτηση «checkNoWater()» ελέγχει την αντλία ώστε να μην λειτουργεί χωρίς νερό και κατά συνέπεια φθαρθεί.

## 4.8 Συνάρτηση algorithmOfIcecubes ()

Η συνάρτηση αυτή είναι ο αλγόριθμος σχηματισμού παγοκύβων.

## 4.9 Συνάρτηση MakeIceCubes ()

Η συνάρτηση αυτή συνδέει όλες τις παραπάνω συναρτήσεις ώστε να λειτουργεί σωστά η παγομηχανή

## 5. Κατασκευή πλακέτας

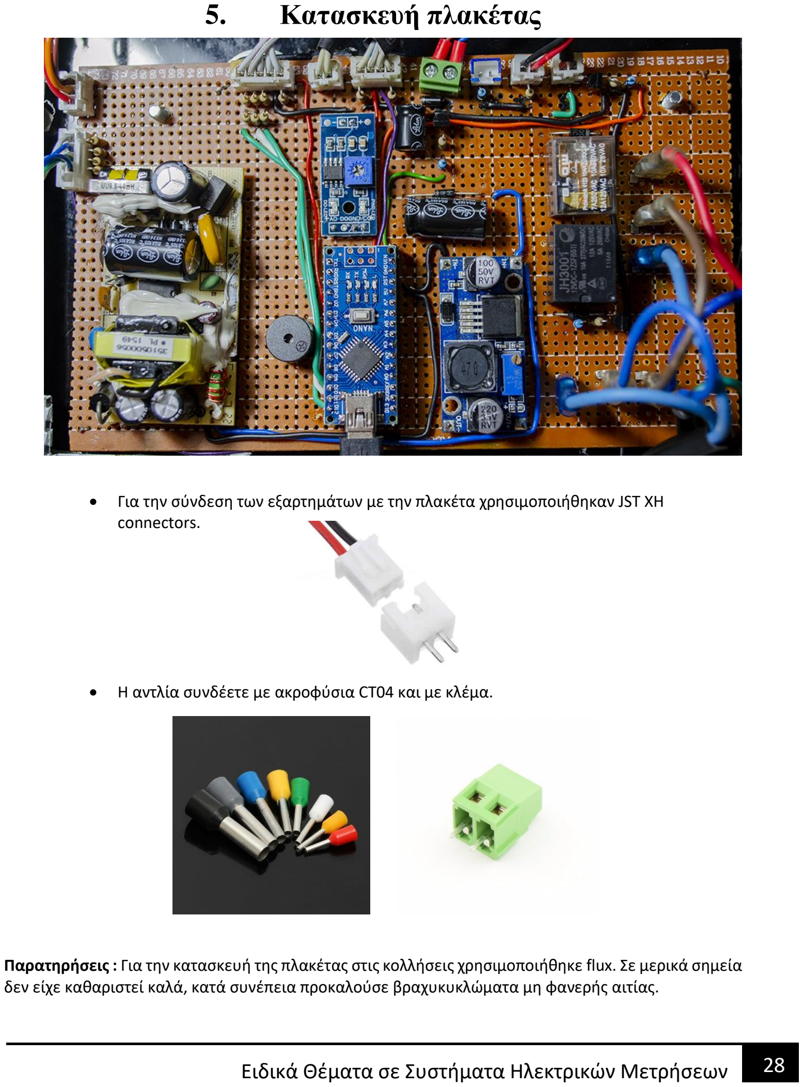
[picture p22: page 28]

- Για την σύνδεση των εξαρτημάτων με την πλακέτα χρησιμοποιήθηκαν JST XH connectors.
- Η αντλία συνδέετε με ακροφύσια CT04 και με κλέμα.

Παρατηρήσεις : Για την κατασκευή της πλακέτας στις κολλήσεις χρησιμοποιήθηκε flux. Σε μερικά σημεία δεν είχε καθαριστεί καλά, κατά συνέπεια προκαλούσε βραχυκυκλώματα μη φανερής αιτίας.

## 6. Indications

## Normal Led Inications

## Abnormal Led Inications

Ice Full LED | Add Water LED | Work LED | Buzzer | Condition
OFF | OFF | ON | - | Making Ice Cubes
OFF | ON | OFF or ON | *buzz | Need Water
ON | OFF | OFF or ON | **buzz | The Tray is full of IceCubes
OFF | OFF | OFF | - | OFF or STBY
Ice Full LED | Add Water LED | Work LED | Buzzer | Condition
*Blinks | *Blinks | *Blinks | ***buzz | The Ice Tray cant Move

## 7. Μέρη παγομηχανής

1. Κουμπιά ελέγχου | 17. Πίσω πλαστικό panel
2. Led indicators | 18. Μεταλλική γωνία στήριξης
3. Θήκη του πάνελ | 19. Ανεμιστήρας
4. Πλαστική βάση | 20. Ψύκτρα
5. Χερούλι | 21. Αντλία νερού
6. Φτυάρι πάγου | 22. Σωλήνας νερού
7. Δοχείο ψύξης νερού | 23. Πλαστικά πόδια
8. Evaporator | 24. Συμπιεστής
9. Σωλήνας νερού | 25. Μεταλλική βάση
10. Μεταλλικές γωνίες | 26. Θήκη του μοτέρ
11. Τερματικοί διακόπτες | 27. Σωλήνας νερού
12. Καπάκι με διαφανές παράθυρο | 28. Βάση στήριξης για το μοτέρ
13. Αριστερό πλαστικό panel | 29. Δεξί πλαστικό panel
14. Φίλτρο | 30. Servo μοτέρ
15. Σωληνοειδές | 31. Καλάθι παγοκύβων
16. Μεταλλική βάση συμπιεστή

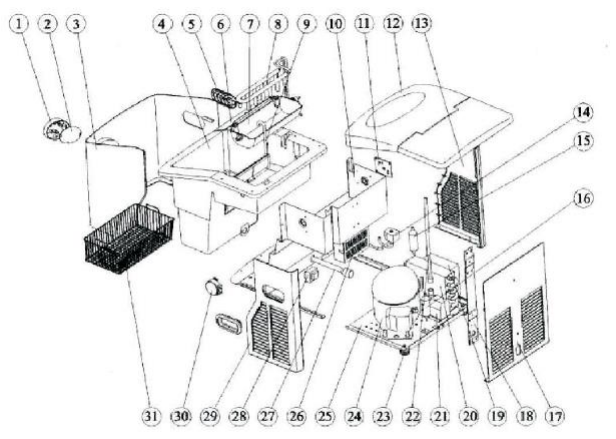
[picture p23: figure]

## 8. Σχηματικό κυκλώματος

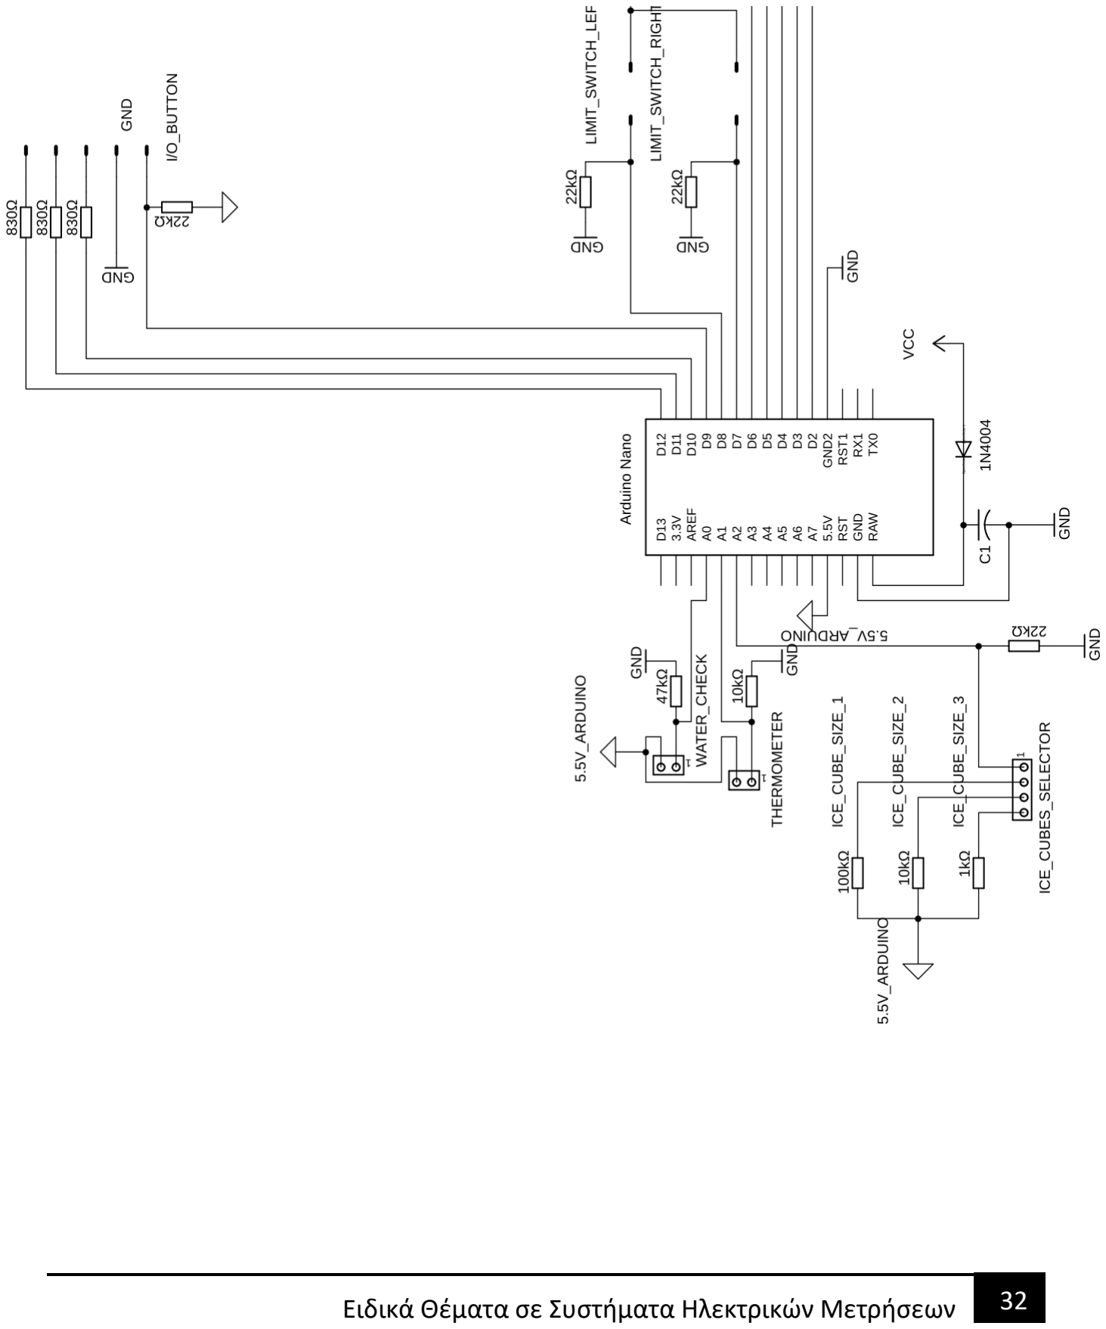
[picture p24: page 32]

## 9. ΣΥΜΠΕΡΑΣΜΑΤΑ

Εν κατακλείδι η μηχανή παγοκύβων λειτουργεί ικανοποιητικά, καθώς υπάρχουν αρκετοί αλγόριθμοι που την προστατεύουν από πιθανά προβλήματα και κινδύνους. Ο κώδικας επικοινωνεί επαρκώς με την κονσόλα του IDE και ενημερώνει το χρήστη για κάθε βήμα που εκτελεί, με αυτόν τον τρόπο είναι πολύ εύκολη η ανίχνευση λαθών. Ο αλγόριθμος της θερμοκρασίας προσεγγίζει την πραγματική θερμοκρασία. Ο μικροεπεξεργαστής δεν είναι κολλημένος στην πλακέτα και οποιοδήποτε πρόβλημα μπορεί να αντιμετωπιστεί με μεγαλύτερη ευκολία. Στην μηχανή αυτή προστέθηκε η επιλογή του μεγέθους παγοκύβων ώστε να διευκολύνει το χρήστη. Ο αισθητήρας που ελέγχει την ύπαρξη νερού στην αντλία λειτουργεί ικανοποιητικά όμως λόγω της υψηλής αντίστασης του νερού υπάρχουν σφάλματα και ενδέχεται να υπάρχει νερό και να μην το αναγνωρίσει. Μια μελλοντική βελτίωση είναι να τοποθετηθεί ένας ενισχυτής ώστε να υπάρχει ενίσχυση αυτού του σήματος για πιο ακριβή αποτελέσματα, όπως και να τοποθετηθούν Led για την ένδειξη του μεγέθους των παγοκύβων.

## 10. ΒΙΒΛΙΟΓΡΑΦΙΑ

[1] Καλαϊτζάκη Κ., Κουτρούλη Ε. "Ηλεκτρικές Μετρήσεις και Αισθητήρες", 2010
[2] Ανάλυση και σχεδίαση αναλογικών ολοκληρωμένων κυκλωμάτων
[3] Datasheet transistor 2n2222 (https://www.alldatasheet.com/view.jsp?Searchword=2n2222)
[4] Επεξεργαστής ATMEGA328P (https://www.alldatasheet.com/view.jsp?Searchword=Atmega328p%20datasheet)
[5] https://www.arduino.cc/reference/en/language/functions/time/millis/

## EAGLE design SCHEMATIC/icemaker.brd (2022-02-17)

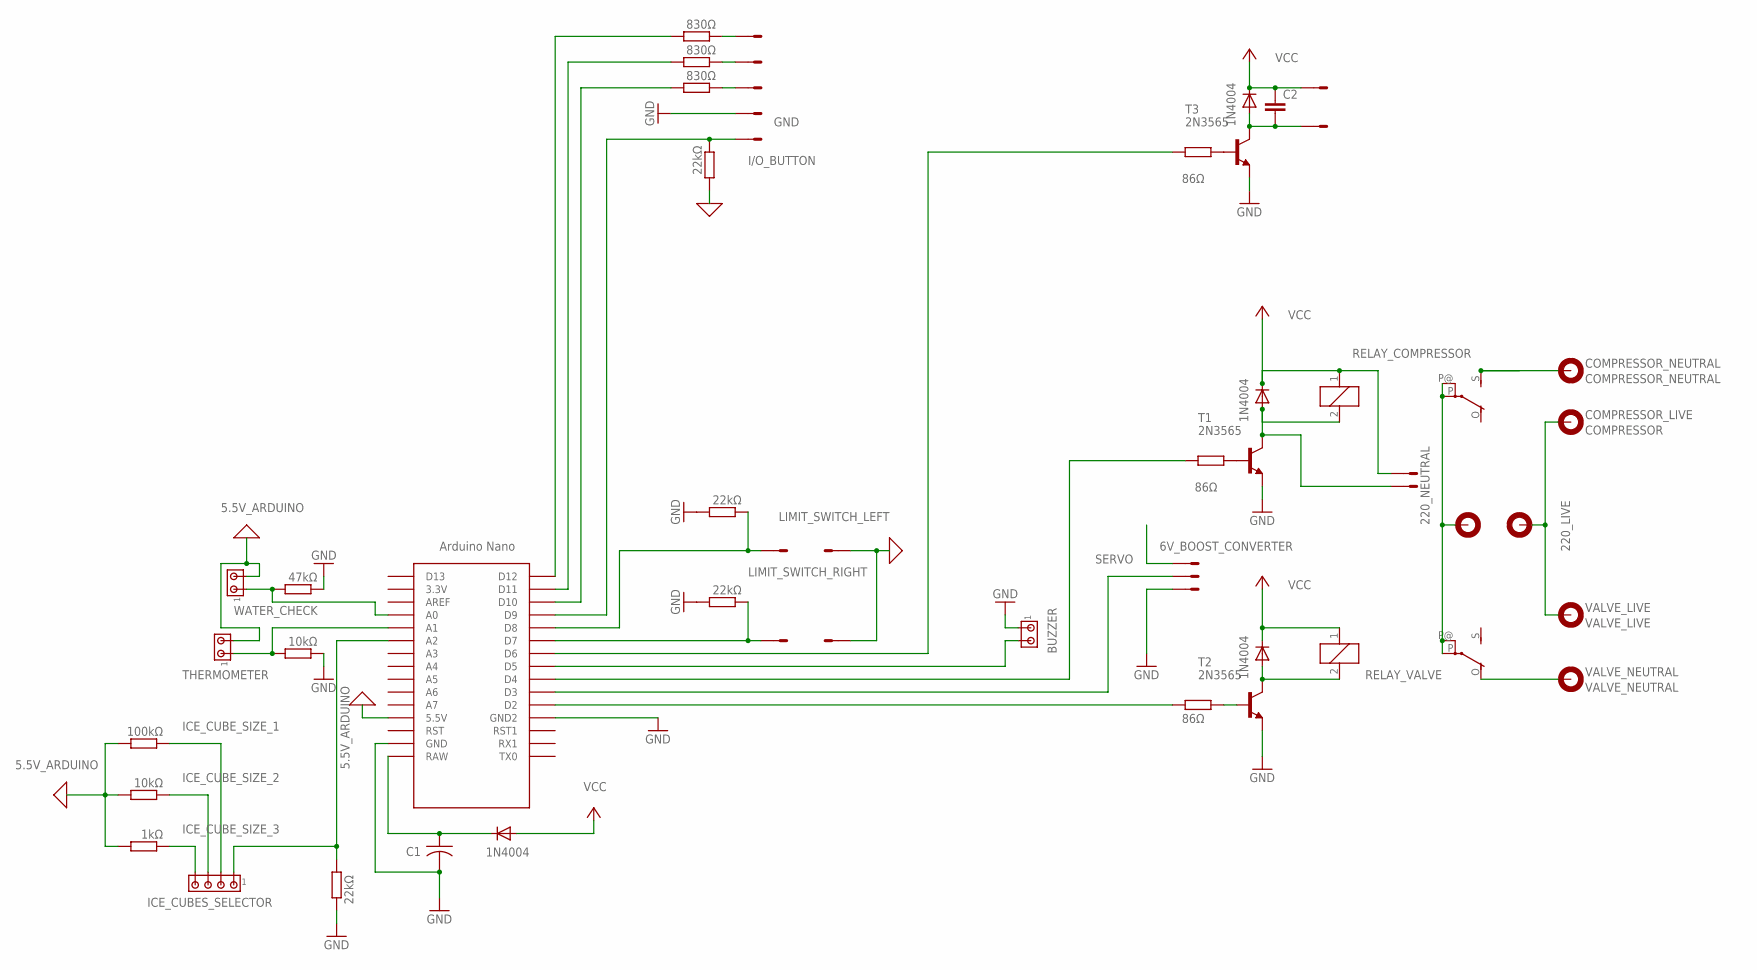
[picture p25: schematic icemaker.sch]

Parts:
220_LIVE: 220_LIVE; 2,8-PAD
220_NEUTRLA: 220_NEUTRAL; 2,8-PAD
BUZZER: MTA02-156; 1X2MTA
C1: C-US050-025X075; C050-025X075
C2: C2,5-3; C2.5-3
COMPRESSOR_LIVE: COMPRESSOR; 2,8-PAD
COMPRESSOR_NEUTRAL: COMPRESSOR_NEUTRAL; 2,8-PAD
D1, D2, D3, D4: 1N4004; DO41-10
FAN: L02P
ICE_CUBES_SELECTOR: MTA04-156; 1X4MTA
LED_WORK: I/O_BUTTON; L05P
PUMP: L02P
R1, R2, R3: 86Ω; 0204/5
R4: 1kΩ; 0204/5
R5: 47kΩ; 0204/5
R6, R13: 10kΩ; 0204/5
R7, R8, R9: 830Ω; 0204/5
R10, R11, R12, R16: 22kΩ; 0204/5
R14: 100kΩ; 0204/5
RELAY_COMPRESSOR: M3XXH
RELAY_VALVE: M3XXH
SERVO: S03P
SV1: L04P
T1, T2, T3: 2N3565; TO92
THERMOMETER: MTA02-156; 1X2MTA
U$1: NANO
VALVE_LIVE: VALVE_LIVE; 2,8-PAD
VALVE_NEUTRAL: VALVE_NEUTRAL; 2,8-PAD
WATER_CHECK: MTA02-156; 1X2MTA

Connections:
5.5V_ARDUINO: R4.2, R10.2, R13.2, R14.2, SV1.2, SV1.3, THERMOMETER.2, U$1.5V (5.5V), WATER_CHECK.2
6V_BOOST_CONVERTER: SERVO.3
220V: 220_LIVE.B2,8, COMPRESSOR_LIVE.B2,8, VALVE_LIVE.B2,8
220_NEUTRAL: 220_NEUTRLA.B2,8, RELAY_COMPRESSOR.P, RELAY_COMPRESSOR.P@, RELAY_VALVE.P, RELAY_VALVE.P@
BUZZER: BUZZER.2, U$1.D5
GND: BUZZER.1, C1.2, LED_WORK.2, R5.1, R6.1, R11.2, R12.2, R16.1, SERVO.1, T1.3 (E), T2.3 (E), T3.3 (E), U$1.GND, U$1.GND1 (GND2)
I/O_BUTTON: LED_WORK.1, R10.1, U$1.D9
ICE_CUBE_SIZE_1: ICE_CUBES_SELECTOR.2, R14.1
ICE_CUBE_SIZE_2: ICE_CUBES_SELECTOR.3, R13.1
ICE_CUBE_SIZE_3: ICE_CUBES_SELECTOR.4, R4.1
LIMIT_SWITCH_LEFT: R11.1, SV1.4, U$1.D8
LIMIT_SWITCH_RIGHT: R12.1, SV1.1, U$1.D7
unnamed: D1.A, RELAY_VALVE.2, T2.1 (C)
unnamed: R3.2, U$1.D2
unnamed: R2.2, U$1.D6
unnamed: R2.1, T3.2 (B)
unnamed: R3.1, T2.2 (B)
unnamed: R1.2, U$1.D4
unnamed: LED_WORK.5, R7.1
unnamed: LED_WORK.4, R8.1
unnamed: R7.2, U$1.D12
unnamed: R8.2, U$1.D11
unnamed: R9.2, U$1.D10
unnamed: LED_WORK.3, R9.1
unnamed: R1.1, T1.2 (B)
unnamed: D2.A, FAN.1, RELAY_COMPRESSOR.2, T1.1 (C)
unnamed: C1.1, D3.C, U$1.RAW
unnamed: RELAY_VALVE.O, VALVE_NEUTRAL.B2,8
unnamed: COMPRESSOR_NEUTRAL.B2,8, RELAY_COMPRESSOR.S
unnamed: ICE_CUBES_SELECTOR.1, R16.2, U$1.A2
unnamed: C2.2, D4.A, PUMP.1, T3.1 (C)
SERVO: SERVO.2, U$1.D3
THERMOMETER: R6.2, THERMOMETER.1, U$1.A1
VCC: C2.1, D1.C, D2.C, D3.A, D4.C, FAN.2, PUMP.2, RELAY_COMPRESSOR.1, RELAY_VALVE.1
WATER_CHECK: R5.2, U$1.A0, WATER_CHECK.1

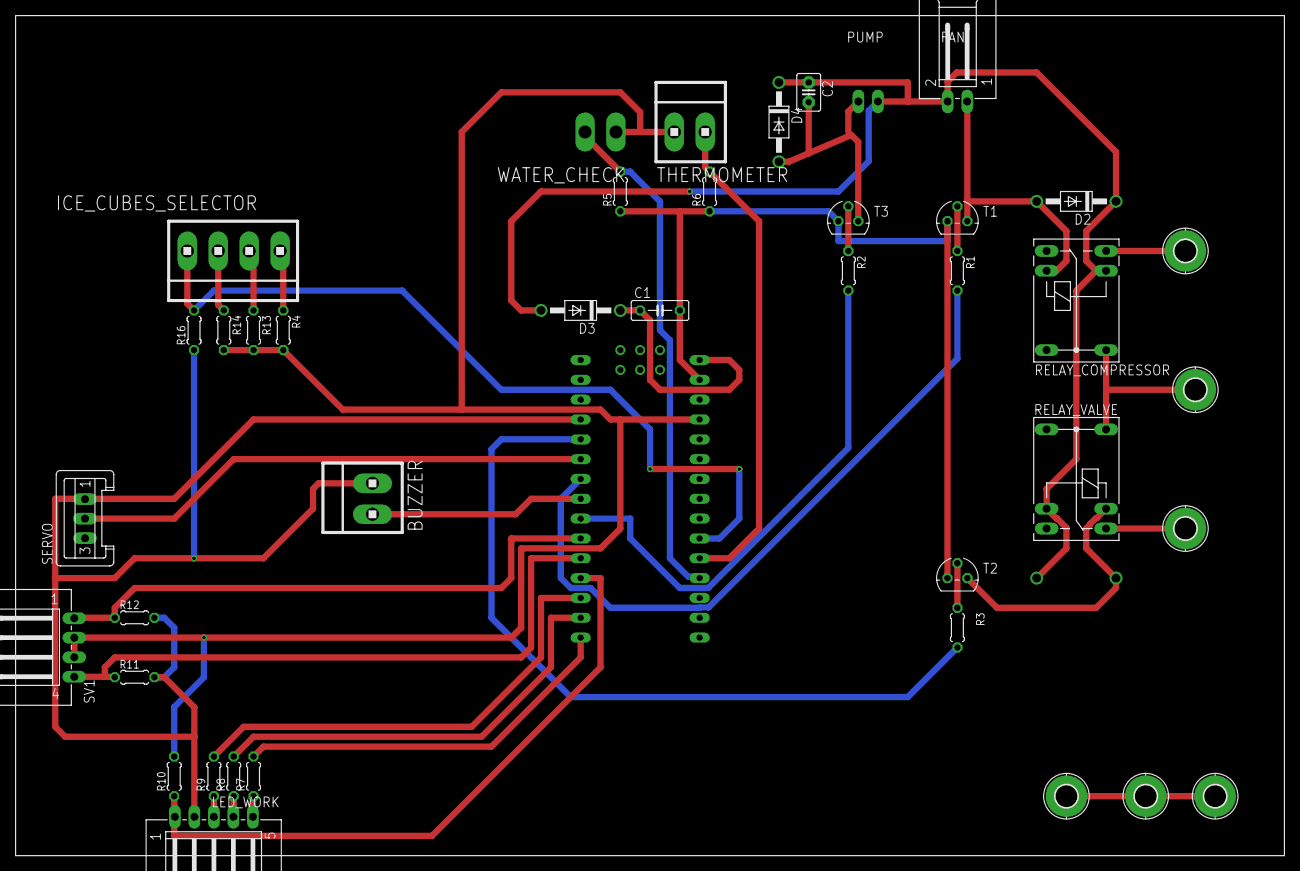
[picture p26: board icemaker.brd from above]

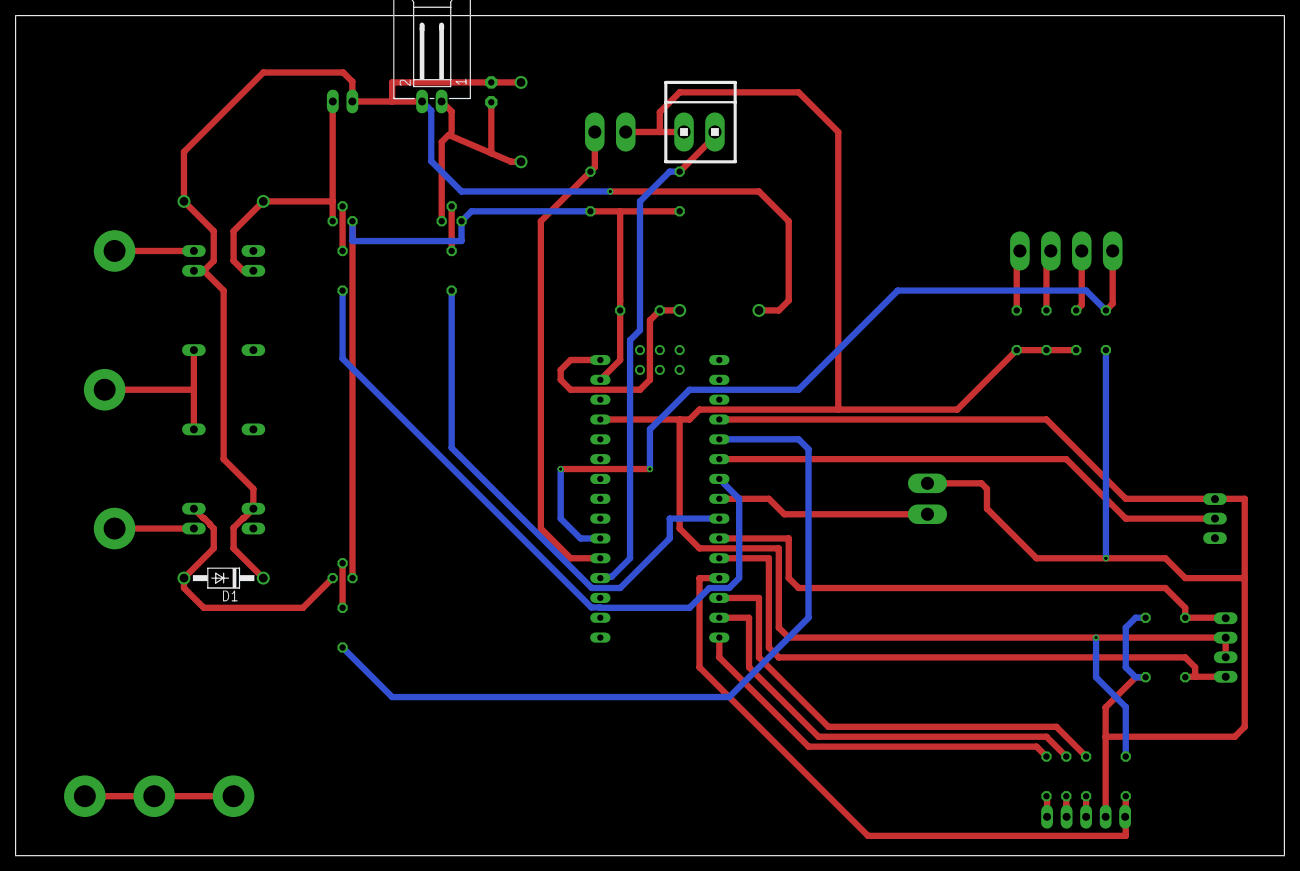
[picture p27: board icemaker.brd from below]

Board: 2 copper layers, 162.5 x 107.6 mm, 42 parts (3 on the bottom side), 34 nets.

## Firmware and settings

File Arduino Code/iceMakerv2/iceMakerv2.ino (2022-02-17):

#include <Servo.h> 

Servo trayMotor;


//pins
//digital input
const int valve=2;
const int servoMotor=3;
const int Compressor=4;
const int buzzer=5;
const int waterPump=6;
const int rightSwitch=7;
const int leftSwitch=8;

const int led_AddWater=10;
const int led_IceFull=11;
const int led_Work=12;

const int led_Small = A3;
const int led_Medium = A4;
const int led_Big = A5;

const int on_off_Button=9;


//analog input
int waterSensor = A0;
int ThermistorPin = A1;
int SelectorButtons = A2;

//variables-constant



//integers
int sizeOfIceCube=3;
int i=0;


  
void setup() {
 Serial.begin(9600);


 //---------------------------
 //connecting the components
 //---------------------------
 
 trayMotor.attach(servoMotor);
 pinMode(valve,OUTPUT);
 pinMode(Compressor,OUTPUT);
 pinMode(buzzer,OUTPUT);
 pinMode(waterPump,OUTPUT);
 pinMode(leftSwitch,INPUT);
 pinMode(rightSwitch,INPUT);
 pinMode(led_Work,OUTPUT);
 pinMode(led_IceFull,OUTPUT);
 pinMode(led_AddWater,OUTPUT);
 pinMode(led_Small,OUTPUT);
 pinMode(led_Medium,OUTPUT);
 pinMode(led_Big,OUTPUT);
 pinMode(on_off_Button,INPUT);

 

//----------INITIALIZE----------------//
 digitalWrite(led_Work,LOW);         //LED WORK off
 digitalWrite(led_IceFull,LOW);      //LED IceFull off
 digitalWrite(led_AddWater,LOW);     //LED AddWater off
 digitalWrite(led_Small,LOW);        //LED Small off
 digitalWrite(led_Medium,LOW);       //LED Medium off
 digitalWrite(led_Big,LOW);          //LED Big off
  
 startUpSound();

 digitalWrite(valve,HIGH);      //heating valve off
 delay(500);
 digitalWrite(Compressor,LOW); //Compressor On
 digitalWrite(led_Big,HIGH);      //heating valve off        
 toTheEndRight();
 toTheEndLeft();
 OkSound();
 LedIceCube();
}



void loop() {

    readButtonSelect();

    if(debounced() == true){
      Serial.println("wait to press button");
      digitalWrite(led_Work,LOW);
      i=0;
    }

    if(debounced() == false){
      if(i==0){
        CommandSound();
        delay(500);
      }
      i=1;
      Serial.println("Button pressed");
      digitalWrite(led_Work,HIGH);
      digitalWrite(led_IceFull,LOW);
      digitalWrite(led_AddWater,LOW);
      
      MakeIceCubes(sizeOfIceCube);
    }
  
}


void LedIceCube(){
  if(sizeOfIceCube==1){
     digitalWrite(led_Small,HIGH);        //LED Small on
     digitalWrite(led_Medium,LOW);       //LED Medium off
     digitalWrite(led_Big,LOW);          //LED Big off
  }
  else if(sizeOfIceCube==2){
     digitalWrite(led_Small,LOW);        //LED Small off
     digitalWrite(led_Medium,HIGH);      //LED Medium on
     digitalWrite(led_Big,LOW);          //LED Big off
  }
  else if(sizeOfIceCube==3){
     digitalWrite(led_Small,LOW);        //LED Small off
     digitalWrite(led_Medium,LOW);       //LED Medium off
     digitalWrite(led_Big,HIGH);         //LED Big on
  }
}
  

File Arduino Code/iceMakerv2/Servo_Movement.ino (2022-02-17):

 //========================servo========================//
 const int speedServoToTheRightMicrosecond=1780;
 const int speedServoToTheLeftMicrosecond=1250;
 const int stopServo=1500;

 //delays 
 const int delayTimeBetween_left_and_right=2000;
 const int maximumTimeForMoving=3000;
 //============================================//
 //   go right until it hit the limit switch   //
 //============================================//
  void toTheEndRight(){
    unsigned long StartTime = millis();
    unsigned long CurrentTime = millis();
    unsigned long ElapsedTime=0;
    
    Serial.println("Going Right");
    int rightSwitchState = digitalRead(rightSwitch);
    Serial.println(rightSwitchState);
    
    if(rightSwitchState==LOW){
    do{
      CurrentTime = millis();
      ElapsedTime = CurrentTime - StartTime;
      
      delay(100);
      rightSwitchState = digitalRead(rightSwitch);
      Serial.println("moving");
      trayMotor.writeMicroseconds(speedServoToTheRightMicrosecond);  //turn right
      
      if(ElapsedTime>maximumTimeForMoving){
        ErrorServoMove();
      }
    }while (rightSwitchState==LOW);
    trayMotor.writeMicroseconds(stopServo); //stop 
    }
  }

 //============================================//
 //    go left until it hit the limit switch   //
 //============================================//
  void toTheEndLeft(){
    unsigned long StartTime = millis();
    unsigned long CurrentTime = millis();
    unsigned long ElapsedTime=0;
    
    Serial.println("Going Left");
    int leftSwitchState = digitalRead(leftSwitch);
    Serial.println(leftSwitchState);
    
    if(leftSwitchState==LOW){
    do{
      CurrentTime = millis();
      ElapsedTime = CurrentTime - StartTime;
      delay(100);
      leftSwitchState = digitalRead(leftSwitch);
      Serial.println("moving");
      trayMotor.writeMicroseconds(speedServoToTheLeftMicrosecond);  //turn left
      if(ElapsedTime>maximumTimeForMoving){
        ErrorServoMove();
      }
    }while (leftSwitchState==LOW);
    Serial.println("stop moving");
    trayMotor.writeMicroseconds(stopServo); //stop 
    }
  }

 //=====================================================================================================================//
 //   empty ice cubes from tray, basicly it is a reciprocating motion and at the end it goes to the original position   //
 //=====================================================================================================================//
  void EmptyIceCubes(){ 
      Serial.println("emptying IceCubes");
      toTheEndLeft();
      delay(delayTimeBetween_left_and_right);
      toTheEndRight();
      delay(delayTimeBetween_left_and_right);
      toTheEndLeft();
    
  }

 //=============================================//
 //     empty the water from tray (go left)     //
 //=============================================//
  void EmptyWaterfromWaterTray(){
    
    if(rightSwitch==LOW && leftSwitch==HIGH){ //If it is on the right position (water hold)
      toTheEndLeft();
    }

    if(rightSwitch==HIGH && leftSwitch==LOW){ //If it is on the left position (empty tray)
    }

    if(rightSwitch==HIGH && leftSwitch==HIGH){ //If it is on the middle
      toTheEndLeft();
    }
    
  }
